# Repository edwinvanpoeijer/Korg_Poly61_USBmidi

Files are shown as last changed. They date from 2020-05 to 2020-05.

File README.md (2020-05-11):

# Korg_Poly61_USBmidi
USB Midi conversion for the Korg Poly61 synthesizer

This midi conversion uses a Teensy V3.2 to interface between the keys, arpeggiator and the cpu board.
This will add the following functionality to your Korg Poly61:

USB Midi interface
Hardware MIDI input
Hardware MIDI thru (from the hardware MIDI input)
Hardware MIDI out/thru (forwarded from the USB midi) 
MIDI synced arpeggiator (can be set to internal,  1/4, 1/8, 1/16, 1/32)
SYNC/TRIGGER out 
MIDI port selectable (1 - 16 or OMNI)

The MIDI port and arpeggiator sync can be set at power on by holding the keys.
C0  = ARP internal
C#0 = ARP 1/4
D0  = ARP 1/8
D#0 = ARP 1/16
E0  = ARP 1/32

C2 = MIDI channel 1 ---> D#3 = MIDI channel 16
E3 = OMNI

I have included the code, schematic and a very raw pcb (i still have some available).
There is a lot of space between the components and the pcb could be half it's current size :)
You will need a Teensy 3.1/3.2 for this as these are still 5V tolerant.

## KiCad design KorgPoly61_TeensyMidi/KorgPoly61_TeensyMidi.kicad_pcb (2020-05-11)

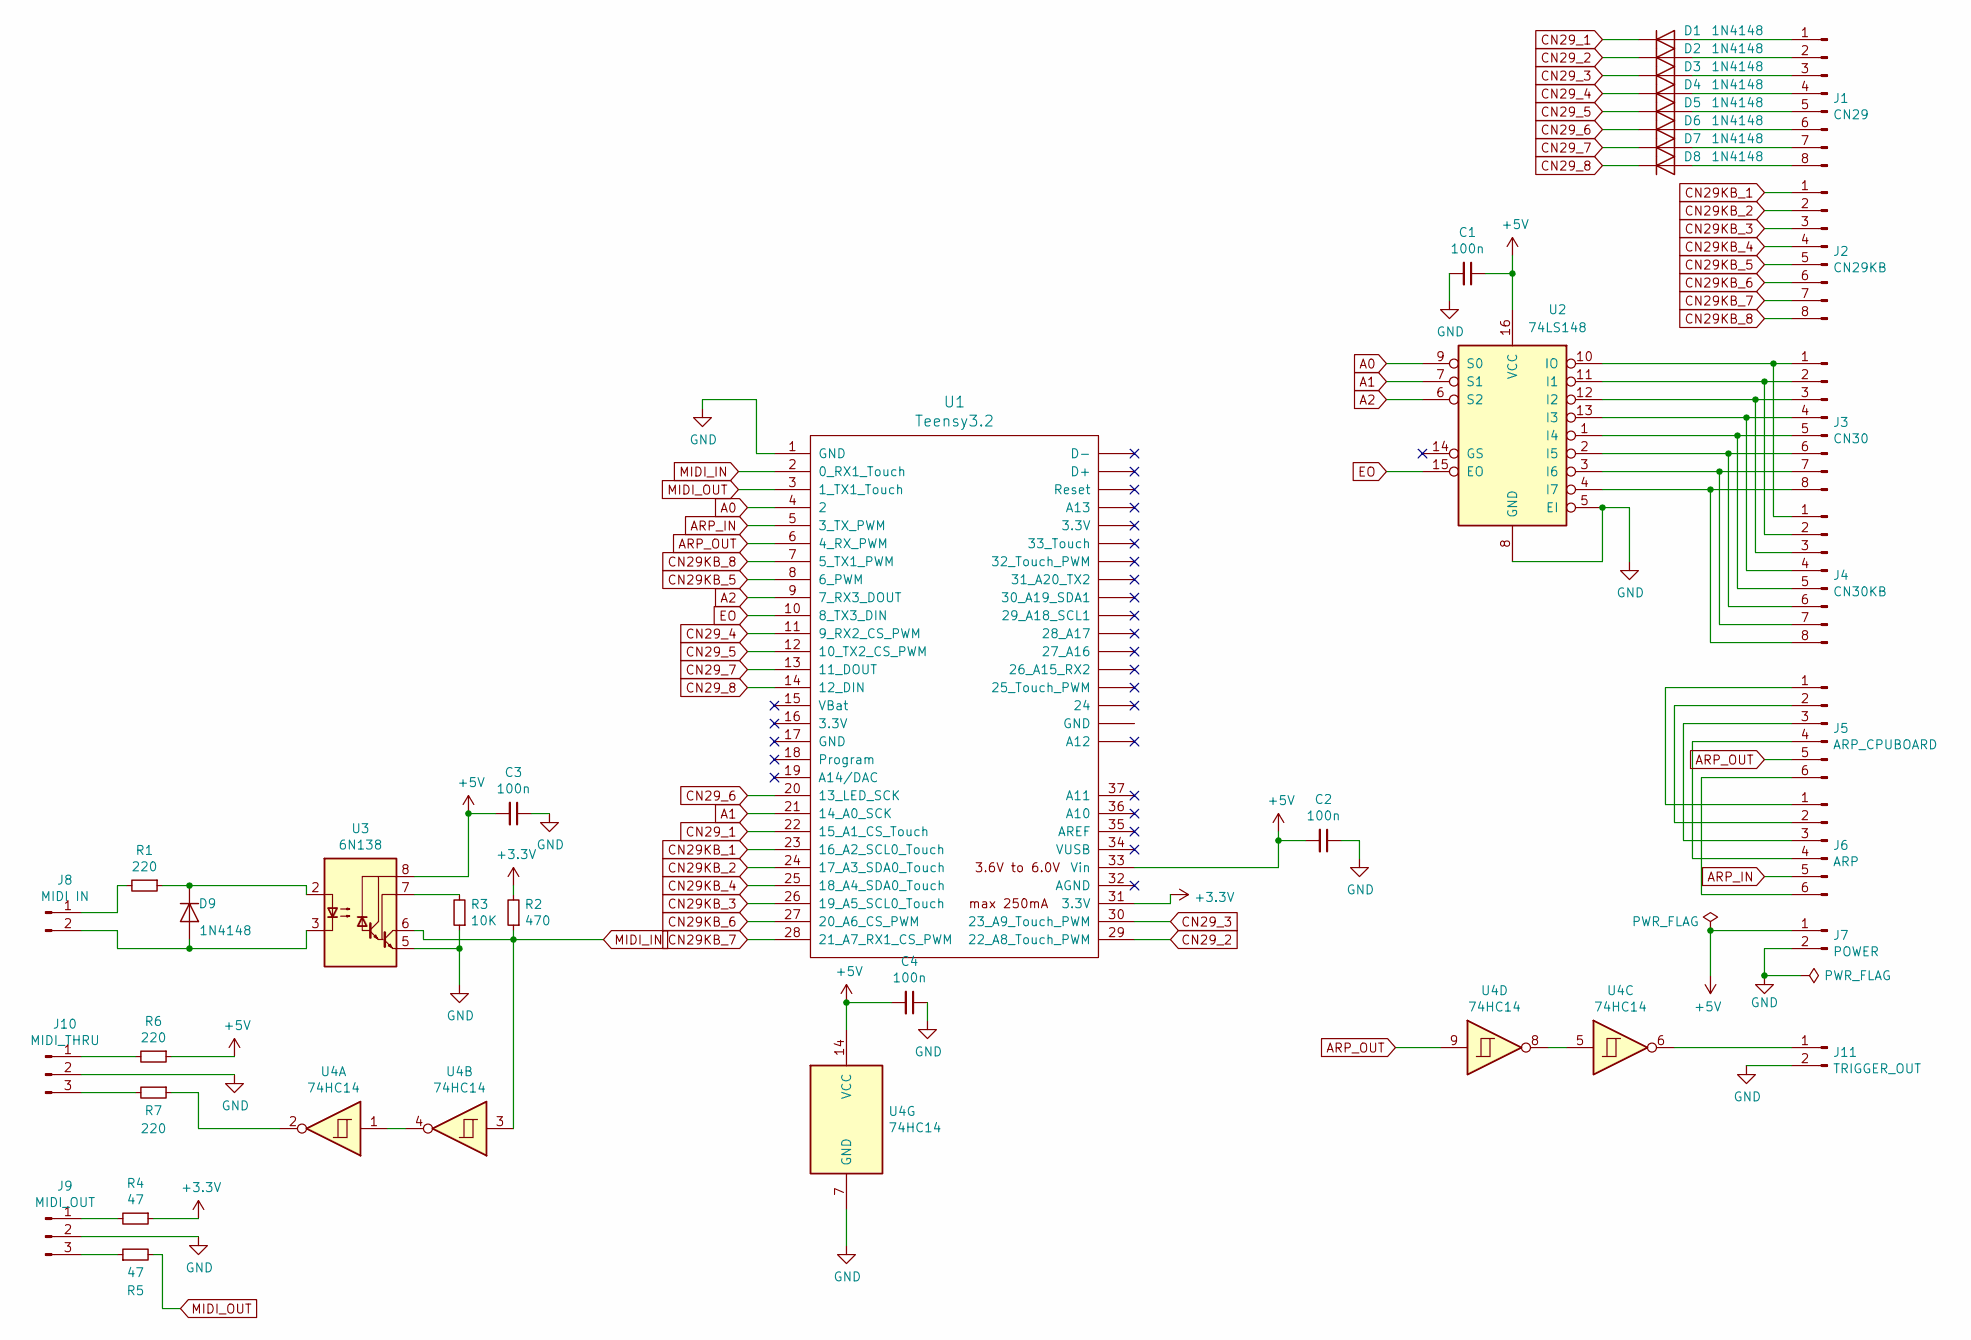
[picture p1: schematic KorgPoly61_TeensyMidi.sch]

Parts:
C1, C2, C3, C4: 100n; C_Disc_D5.0mm_W2.5mm_P5.00mm
D1, D2, D3, D4, D5, D6, D7, D8, D9: 1N4148; D_DO-15_P10.16mm_Horizontal
J1: CN29; PinHeader_1x08_P2.54mm_Vertical
J2: CN29KB; PinHeader_1x08_P2.54mm_Vertical
J3: CN30; PinHeader_1x08_P2.54mm_Vertical
J4: CN30KB; PinHeader_1x08_P2.54mm_Vertical
J5: ARP_CPUBOARD; PinHeader_1x06_P2.54mm_Vertical
J6: ARP; PinHeader_1x06_P2.54mm_Vertical
J7: POWER; PinHeader_1x02_P2.54mm_Vertical
J8: MIDI IN; PinHeader_1x02_P2.54mm_Vertical
J9: MIDI_OUT; PinHeader_1x03_P2.54mm_Vertical
J10: MIDI_THRU; PinHeader_1x03_P2.54mm_Vertical
J11: TRIGGER_OUT; PinHeader_1x02_P2.54mm_Vertical
R1, R6, R7: 220; R_Axial_DIN0207_L6.3mm_D2.5mm_P7.62mm_Horizontal
R2: 470; R_Axial_DIN0207_L6.3mm_D2.5mm_P7.62mm_Horizontal
R3: 10K; R_Axial_DIN0207_L6.3mm_D2.5mm_P7.62mm_Horizontal
R4, R5: 47; R_Axial_DIN0207_L6.3mm_D2.5mm_P7.62mm_Horizontal
U1: Teensy3.2; Teensy30_31_32_LC
U2: 74LS148; DIP-16_W7.62mm_Socket
U3: 6N138; DIP-8_W7.62mm
U4: 74HC14; DIP-14_W7.62mm_Socket

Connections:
+3V3: R2.2, R4.1, U1.31 (3.3V)
+5V: C1.1, C2.2, C3.2, C4.2, J7.1, R6.1, U1.33 (Vin), U2.16 (VCC), U3.8 (VCC), U4.14 (VCC)
A0: U1.4 (2), U2.9 (S0)
A1: U1.21 (14_A0_SCK), U2.7 (S1)
A2: U1.9 (7_RX3_DOUT), U2.6 (S2)
ARP_IN: J6.5, U1.5 (3_TX_PWM)
ARP_OUT: J5.5, U1.6 (4_RX_PWM), U4.9
CN29KB_1: J2.1, U1.23 (16_A2_SCL0_Touch)
CN29KB_2: J2.2, U1.24 (17_A3_SDA0_Touch)
CN29KB_3: J2.3, U1.26 (19_A5_SCL0_Touch)
CN29KB_4: J2.4, U1.25 (18_A4_SDA0_Touch)
CN29KB_5: J2.5, U1.8 (6_PWM)
CN29KB_6: J2.6, U1.27 (20_A6_CS_PWM)
CN29KB_7: J2.7, U1.28 (21_A7_RX1_CS_PWM)
CN29KB_8: J2.8, U1.7 (5_TX1_PWM)
CN29_1: D1.1 (K), U1.22 (15_A1_CS_Touch)
CN29_2: D2.1 (K), U1.29 (22_A8_Touch_PWM)
CN29_3: D3.1 (K), U1.30 (23_A9_Touch_PWM)
CN29_4: D4.1 (K), U1.11 (9_RX2_CS_PWM)
CN29_5: D5.1 (K), U1.12 (10_TX2_CS_PWM)
CN29_6: D6.1 (K), U1.20 (13_LED_SCK)
CN29_7: D7.1 (K), U1.13 (11_DOUT)
CN29_8: D8.1 (K), U1.14 (12_DIN)
EO: U1.10 (8_TX3_DIN), U2.15 (EO)
GND: C1.2, C2.1, C3.1, C4.1, J7.2, J9.2, J10.2, J11.2, R3.1, U1.1 (GND), U2.5 (EI), U2.8 (GND), U3.5 (GND), U4.7 (GND)
MIDI_IN: R2.1, U1.2 (0_RX1_Touch), U3.6 (VO2), U4.3
MIDI_OUT: R5.2, U1.3 (1_TX1_Touch)
unnamed: D1.2 (A), J1.1
unnamed: D2.2 (A), J1.2
unnamed: D3.2 (A), J1.3
unnamed: D4.2 (A), J1.4
unnamed: D5.2 (A), J1.5
unnamed: D6.2 (A), J1.6
unnamed: D7.2 (A), J1.7
unnamed: D8.2 (A), J1.8
unnamed: D9.1 (K), R1.1, U3.2 (C1)
unnamed: D9.2 (A), J8.2, U3.3 (C2)
unnamed: J3.1, J4.1, U2.10 (IO)
unnamed: J3.2, J4.2, U2.11 (I1)
unnamed: J3.3, J4.3, U2.12 (I2)
unnamed: J3.4, J4.4, U2.13 (I3)
unnamed: J3.5, J4.5, U2.1 (I4)
unnamed: J3.6, J4.6, U2.2 (I5)
unnamed: J3.7, J4.7, U2.3 (I6)
unnamed: J3.8, J4.8, U2.4 (I7)
unnamed: J5.1, J6.1
unnamed: J5.2, J6.2
unnamed: J5.3, J6.3
unnamed: J5.4, J6.4
unnamed: J5.6, J6.6
unnamed: J8.1, R1.2
unnamed: J9.1, R4.2
unnamed: J9.3, R5.1
unnamed: J10.1, R6.2
unnamed: J10.3, R7.2
unnamed: J11.1, U4.6
unnamed: R3.2, U3.7 (VO1)
unnamed: R7.1, U4.2
unnamed: U4.1, U4.4
unnamed: U4.5, U4.8

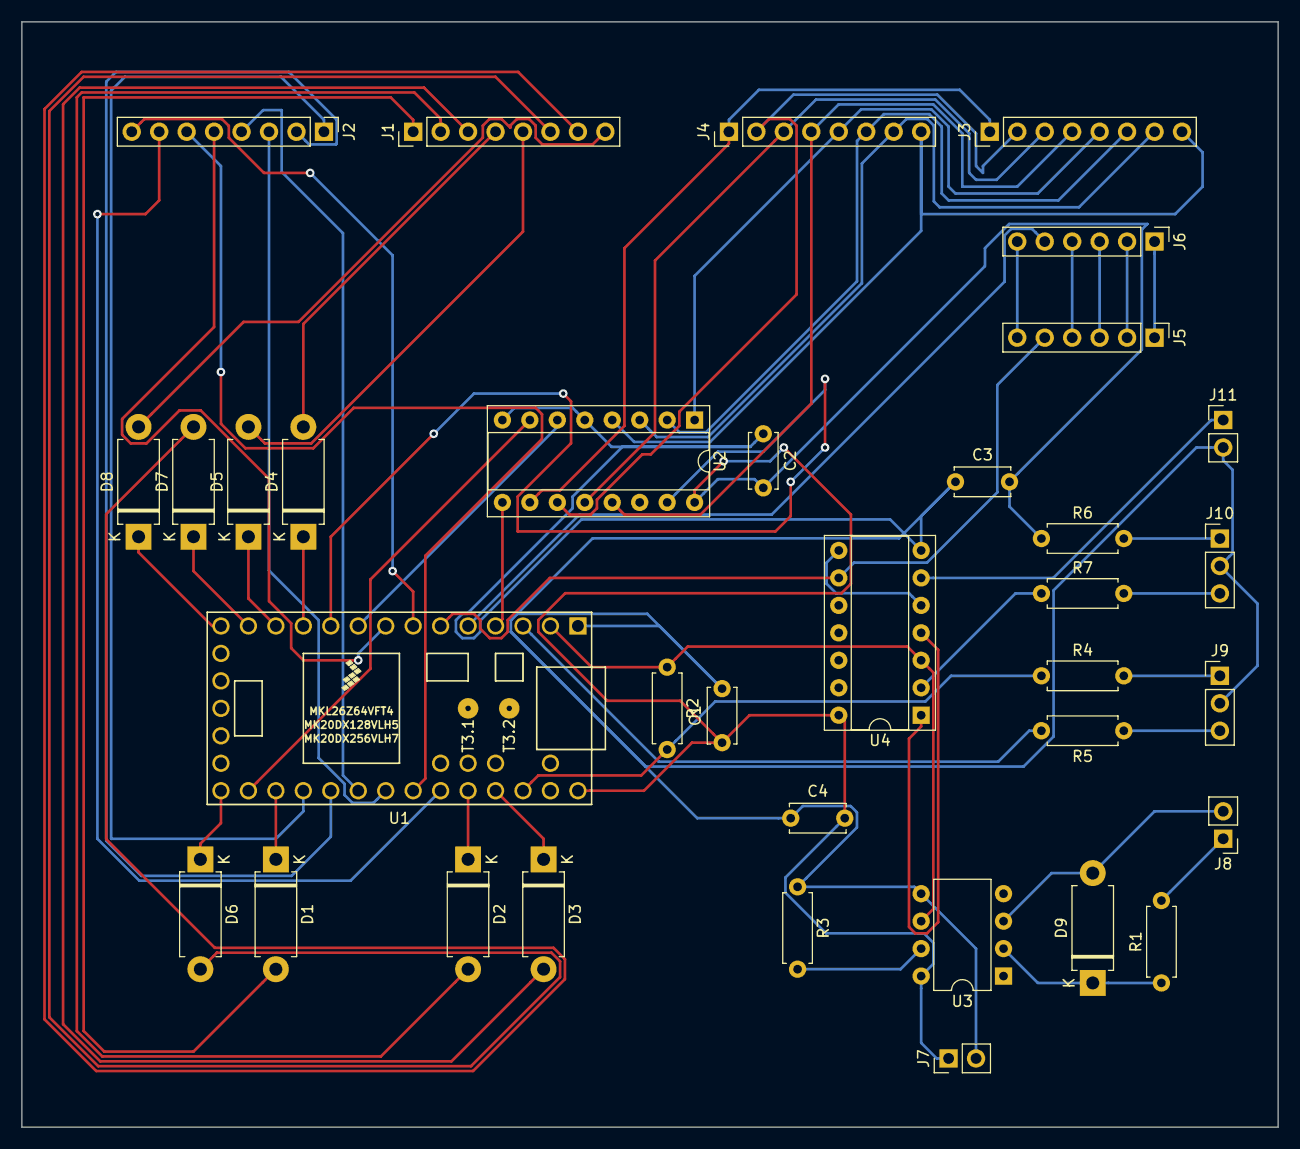
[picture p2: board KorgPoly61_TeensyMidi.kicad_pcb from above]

Board: 2 copper layers, 116.2 x 102.2 mm, 35 parts (0 on the bottom side), 60 nets.

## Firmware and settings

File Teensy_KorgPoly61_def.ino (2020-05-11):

/* Receive Incoming USB MIDI using functions.  As usbMIDI
   reads incoming messages, handler functions are run.
   See the InputRead example for the non-function alterative.

   This small example shows only 3 common messages, to keep
   things simple.  See InputFunctionsComplete for an example
   with all possible messages.

   Use the Arduino Serial Monitor to view the messages
   as Teensy receives them by USB MIDI

   You must select MIDI from the "Tools > USB Type" menu

   This example code is in the public domain.
*/

#include <MIDI.h>
#include <EEPROM.h>

// HW midi instance
MIDI_CREATE_INSTANCE(HardwareSerial, Serial1, MIDI);

// Tables for fast processing
byte keyArray[] = {B11111111, B11111111, B11111111, B11111111, B11111111, B11111111, B11111111, B11111111};
byte kbReadArray[] = {B11111111, B11111111, B11111111, B11111111, B11111111, B11111111, B11111111};
byte keyArrayMaskOn[]  = {B01111111, B10111111, B11011111, B11101111, B11110111, B11111011, B11111101, B11111110};
byte keyArrayMaskOff[] = {B10000000, B01000000, B00100000, B00010000, B00001000, B00000100, B00000010, B00000001};
byte bitPos[] = {4, 5, 6, 7, 0, 1, 2, 3, 4, 5, 6, 7, 0, 1, 2, 3, 4, 5, 6, 7, 0, 1, 2, 3, 4, 5, 6, 7, 0, 1, 2, 3, 4, 5, 6, 7, 0, 1, 2, 3, 4, 5, 6, 7, 0, 1, 2, 3, 4, 5, 6, 7, 0, 1, 2, 3, 4, 5, 6, 7, 0, 1, 2, 3, 4, 5, 6, 7, 0, 1, 2, 3, 4, 5, 6, 7, 0, 1, 2, 3, 4, 5, 6, 7, 0, 1, 2, 3, 4, 5, 6, 7, 0, 1, 2, 3, 4, 5, 6, 7, 0, 1, 2, 3, 4, 5, 6, 7, 0, 1, 2, 3, 4, 5, 6, 7, 0, 1, 2, 3, 4, 5, 6, 7, 0, 1, 2, 3};
byte keyArrayNum[]      = {0, 0, 0, 0, 0, 0, 0, 0, 0, 0, 0, 0, 0, 0, 0, 0, 0, 0, 0, 0, 0, 0, 0, 0, 0, 0, 0, 0, 0, 0, 0, 0, 0, 0, 0, 0, 0, 0, 0, 0, 0, 0, 0, 0, 1, 1, 1, 1, 1, 1, 1, 1, 2, 2, 2, 2, 2, 2, 2, 2, 3, 3, 3, 3, 3, 3, 3, 3, 4, 4, 4, 4, 4, 4, 4, 4, 5, 5, 5, 5, 5, 5, 5, 5, 6, 6, 6, 6, 6, 6, 6, 6, 7, 7, 7, 7, 7, 7, 7, 7, 7, 7, 7, 7, 7, 7, 7, 7, 7, 7, 7, 7, 7, 7, 7, 7, 7, 7, 7, 7, 7, 7, 7, 7, 7, 7, 7, 7};

// Output (CN29) = PORT c
const byte CN29_0 = 15;
const byte CN29_1 = 22;
const byte CN29_2 = 23;
const byte CN29_3 = 9;
const byte CN29_4 = 10;
const byte CN29_5 = 13;
const byte CN29_6 = 11;
const byte CN29_7 = 12;

// Input (CN30) = PORT D
const byte CN30_0 = 2;
const byte CN30_1 = 14;
const byte CN30_2 = 7;
const byte CN30_3 = 8;

// Input from keyboard (CN30)
// Bits 0-3 PORTB
const byte CN30_KB_0 = 16;
const byte CN30_KB_1 = 17;
const byte CN30_KB_2 = 19;
const byte CN30_KB_3 = 18;
// Bits 4-7 PORTD
const byte CN30_KB_4 = 6;
const byte CN30_KB_5 = 20;
const byte CN30_KB_6 = 21;
const byte CN30_KB_7 = 5;

// Arp sync in
const byte arpIn = 3;
const byte arpOut = 4;
bool arpPulse;
bool midiArp;
byte midiClockCnt;
byte midiClockEnd;
const byte arpQuarterNote = 24;
const byte arpEightNote = 12;
const byte arpSixteenthNote = 6;
const byte arpThirtyTwoNote = 3;
const byte arpPoly61 = 0;
byte midiChannel;
bool powerOnMode;
int  powerOnCounter;
bool bootMode;
int bootCounter;
void setup() {

  // Read midichannel
  midiChannel = EEPROM.read(0);
  if (midiChannel > 16)
  {
    EEPROM.write(0, 0);
    midiChannel = 0;
  }
  // Read arp
  midiClockEnd = EEPROM.read(1);
  if (midiClockEnd == arpQuarterNote || midiClockEnd == arpEightNote || midiClockEnd == arpSixteenthNote || midiClockEnd == arpThirtyTwoNote) {
    midiArp = true;
  }
  else if (midiClockEnd == arpPoly61) {
    midiArp = false;
  }
  else {
    EEPROM.write(1, 0);
    midiClockEnd = arpPoly61;

  }
  // SET CN30 to input
  pinMode( CN30_0, INPUT_PULLUP);
  pinMode( CN30_1, INPUT_PULLUP);
  pinMode( CN30_2, INPUT_PULLUP);
  pinMode( CN30_3, INPUT_PULLUP);

  // Set CN30_KB to input
  pinMode( CN30_KB_0, INPUT_PULLUP);
  pinMode( CN30_KB_1, INPUT_PULLUP);
  pinMode( CN30_KB_2, INPUT_PULLUP);
  pinMode( CN30_KB_3, INPUT_PULLUP);
  pinMode( CN30_KB_4, INPUT_PULLUP);
  pinMode( CN30_KB_5, INPUT_PULLUP);
  pinMode( CN30_KB_6, INPUT_PULLUP);
  pinMode( CN30_KB_7, INPUT_PULLUP);

  // Set CN29 to output
  pinMode( CN29_0, OUTPUT);
  pinMode( CN29_1, OUTPUT);
  pinMode( CN29_2, OUTPUT);
  pinMode( CN29_3, OUTPUT);
  pinMode( CN29_4, OUTPUT);
  pinMode( CN29_5, OUTPUT);
  pinMode( CN29_6, OUTPUT);
  pinMode( CN29_7, OUTPUT);

  pinMode(arpIn, INPUT_PULLUP);
  pinMode(arpOut, OUTPUT);
  //digitalWriteFast(arpOut,LOW);
  arpPulse = false;
  midiClockCnt = 0;
  //midiArp = false;
  //midiClockEnd = arpSixteenthNote;

  Serial.begin(115200);

  Serial1.setTX(1);
  Serial1.setRX(0);
  MIDI.begin();
  MIDI.setHandleNoteOn(myNoteOn);
  MIDI.setHandleNoteOff(myNoteOff);
  MIDI.setHandleControlChange(myControlChange);
  MIDI.setHandleProgramChange(myProgramChange);
  MIDI.setHandleClock(myClock);
  MIDI.setHandleStart(myStart);
  MIDI.setHandleContinue(myContinue);
  MIDI.setHandleStop(myStop);

  usbMIDI.setHandleNoteOn(myNoteOn);
  usbMIDI.setHandleNoteOff(myNoteOff);
  usbMIDI.setHandleControlChange(myControlChange);
  usbMIDI.setHandleProgramChange(myProgramChange);
  usbMIDI.setHandleClock(myClock);
  usbMIDI.setHandleStart(myStart);
  usbMIDI.setHandleContinue(myContinue);
  usbMIDI.setHandleStop(myStop);


  //startupKeyBoardScanner();
  bootMode = true;
  bootCounter = 100;
}

void loop() {

  runningKeyBoardScanner();


  // Check if midiArp is turned off
  if (!midiArp) {
    digitalWrite(arpOut, digitalRead(arpIn));
  }
  else {
    digitalWrite(arpOut, arpPulse);
  }
  // Read  midi
    MIDI.read();
if (usbMIDI.read()) {
    // get the USB MIDI message, defined by these 5 numbers (except SysEX)
    byte type = usbMIDI.getType();
    byte channel = usbMIDI.getChannel();
    byte data1 = usbMIDI.getData1();
    byte data2 = usbMIDI.getData2();
    byte cable = 0;

    // forward this message to 1 of the 3 Serial MIDI OUT ports
    if (type != usbMIDI.SystemExclusive) {
      // Normal messages, first we must convert usbMIDI's type (an ordinary
      // byte) to the MIDI library's special MidiType.
      midi::MidiType mtype = (midi::MidiType)type;

      // Then simply give the data to the MIDI library send()
      switch (cable) {
        case 0:
          MIDI.send(mtype, data1, data2, channel);
          break;
        case 1:
          break;
        case 2:
          break;
      }

    } else {
      // SysEx messages are special.  The message length is given in data1 & data2
      unsigned int SysExLength = data1 + data2 * 256;
      switch (cable) {
        case 0:
          MIDI.sendSysEx(SysExLength, usbMIDI.getSysExArray(), true);
          break;
        case 1:
          break;
        case 2:
          break;
      }
    }
    
  }
}

void runningKeyBoardScanner()
{
  GPIOC_PDOR = 255;
  bool allDone = false;
  while (!allDone)
  {
    byte bRead =  (GPIOD_PDIR & 0xFF) & B00001111;
    byte kbRead = (GPIOB_PDIR & 0xFF) & B00001111;
    kbRead      = (kbRead | (GPIOD_PDIR & 0xFF) & B11110000);
    if      (bRead == B00000111) {
      allDone = true;
      GPIOC_PDOR = 255;
    }
    else if (bRead == B00001111)  {
      GPIOC_PDOR = keyArray[7] & kbRead;
      kbReadArray[7] = kbRead;
    }
    else if (bRead == B00001110)  {
      GPIOC_PDOR = keyArray[6] & kbRead;
      kbReadArray[6] = kbRead;
    }
    else if (bRead == B00001101)  {
      GPIOC_PDOR = keyArray[5] & kbRead;
      kbReadArray[5] = kbRead;
    }
    else if (bRead == B00001100)  {
      GPIOC_PDOR = keyArray[4] & kbRead;
      kbReadArray[4] = kbRead;
    }
    else if (bRead == B00001011)  {
      GPIOC_PDOR = keyArray[3] & kbRead;
      kbReadArray[3] = kbRead;
    }
    else if (bRead == B00001010)  {
      GPIOC_PDOR = keyArray[2] & kbRead;
      kbReadArray[2] = kbRead;
    }
    else if (bRead == B00001001)  {
      GPIOC_PDOR = keyArray[1] & kbRead;
      kbReadArray[1] = kbRead;
    }
    else if (bRead == B00001000)  {
      GPIOC_PDOR = keyArray[0] & kbRead;
      kbReadArray[0] = kbRead;
    }
    else {
      GPIOC_PDOR = 255;
    }
  }
  if (bootMode)
  {
    bootCounter = bootCounter - 1;
    if (bootCounter == 0)
    {
      bootMode = false;
    }
  }

  if (bootMode)
  {
    // Check arp 
    switch (kbReadArray[0]) {
      case B01111111: midiArp = false; midiClockEnd = arpPoly61; EEPROM.write(1, midiClockEnd); break;
      case B10111111: midiArp = true; midiClockEnd = arpQuarterNote ; midiClockCnt = 0; EEPROM.write(1, midiClockEnd); break;
      case B11011111: midiArp = true; midiClockEnd = arpEightNote ; midiClockCnt = 0; EEPROM.write(1, midiClockEnd); break;
      case B11101111: midiArp = true; midiClockEnd = arpSixteenthNote ; midiClockCnt = 0; EEPROM.write(1, midiClockEnd); break;
      case B11110111: midiArp = true; midiClockEnd = arpThirtyTwoNote ; midiClockCnt = 0; EEPROM.write(1, midiClockEnd); break;
      case B11111011: break;
      case B11111101: break;
      case B11111110: break;
    }
    // Check midi receive channel (1-16 - Omni
    switch (kbReadArray[3]) {
      case B01111111: midiChannel = 1; EEPROM.write(0, midiChannel); break;
      case B10111111: midiChannel = 2; EEPROM.write(0, midiChannel); break;
      case B11011111: midiChannel = 3; EEPROM.write(0, midiChannel); break;
      case B11101111: midiChannel = 4; EEPROM.write(0, midiChannel); break;
      case B11110111: midiChannel = 5; EEPROM.write(0, midiChannel); break;
      case B11111011: midiChannel = 6; EEPROM.write(0, midiChannel); break;
      case B11111101: midiChannel = 7; EEPROM.write(0, midiChannel); break;
      case B11111110: midiChannel = 8; EEPROM.write(0, midiChannel); break;
    }
    switch (kbReadArray[4]) {
      case B01111111: midiChannel = 9; EEPROM.write(0, midiChannel); break;
      case B10111111: midiChannel = 10; EEPROM.write(0, midiChannel); break;
      case B11011111: midiChannel = 11; EEPROM.write(0, midiChannel); break;
      case B11101111: midiChannel = 12; EEPROM.write(0, midiChannel); break;
      case B11110111: midiChannel = 13; EEPROM.write(0, midiChannel); break;
      case B11111011: midiChannel = 14; EEPROM.write(0, midiChannel); break;
      case B11111101: midiChannel = 15; EEPROM.write(0, midiChannel); break;
      case B11111110: midiChannel = 16; EEPROM.write(0, midiChannel); break;
    }
    switch (kbReadArray[5]) {
      case B01111111: midiChannel = 0; EEPROM.write(0, midiChannel); break;
      case B10111111: midiChannel = 10; break;
      case B11011111: midiChannel = 11; break;
      case B11101111: midiChannel = 12; break;
      case B11110111: midiChannel = 13; break;
      case B11111011: midiChannel = 14; break;
      case B11111101: midiChannel = 15; break;
      case B11111110: midiChannel = 16; break;
    }

  }
}
void myNoteOn(byte channel, byte note, byte velocity) {
  if (channel == 0 || channel == midiChannel) {
  keyArray[(keyArrayNum[note])] = keyArray[(keyArrayNum[note])] & keyArrayMaskOn[(bitPos[note])];
  }
}

void myNoteOff(byte channel, byte note, byte velocity) {
    if (channel == 0 || channel == midiChannel) {
  keyArray[(keyArrayNum[note])] = keyArray[(keyArrayNum[note])] | keyArrayMaskOff[(bitPos[note])];
    }
}

void myControlChange(byte channel, byte control, byte value) {

}

void myClock() {
  midiClockCnt++;
  if (midiClockCnt >= midiClockEnd) {
    midiClockCnt = 0;
    arpPulse = true;
  }
  else {
    arpPulse = false;
  }
}

void myStart() {
  midiClockCnt = 0;
}

void myContinue() {
  midiClockCnt = 0;
}

void myStop() {
  midiClockCnt = 0;
}

void myProgramChange(byte channel, byte number)
{
    if (channel == 0 || channel == midiChannel) {
  switch (number) {
    case 0: midiArp = false; break;
    case 1: midiArp = true; midiClockEnd = arpQuarterNote ; midiClockCnt = 0; break;
    case 2: midiArp = true; midiClockEnd = arpEightNote ; midiClockCnt = 0; break;
    case 3: midiArp = true; midiClockEnd = arpSixteenthNote ; midiClockCnt = 0; break;
    case 4: midiArp = true; midiClockEnd = arpThirtyTwoNote ; midiClockCnt = 0; break;
  }
    }
}
